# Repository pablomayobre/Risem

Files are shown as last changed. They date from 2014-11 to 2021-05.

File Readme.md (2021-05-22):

# Risem

[Risem](https://positive07.github.io/Risem/) is the final school project that we (my team and I) will work on.

We go to a Technical School and in our last year in this Highschool we make a final project to show the things that we learned over the last six years.

## Team

The team is composed by three persons:

*    Gutierrez Bianchi, Mora
*    Mayobre, Pablo Ariel
*    Mazzocca, Franco Gabriel

We are all students at the ESETP N°748 in Trelew, Chubut - Argentina, in the Electronics career. We are all 17 and in our last year of highschool (2014).

## The project

The school already has a Radio Station, with a HUGE Power Supply, a [Yaesu FT-857D](http://www.yaesu.com/indexVS.cfm?cmd=DisplayProducts&ProdCatID=102&encProdID=8CBB7C4BDBAF40129AD4253A4987523C) and other equipment.

Our aim is to use this station to receive images from the [NOAA Satellites](http://www.n2yo.com/satellites/?c=4), this can be done using a [Quadrifilar Helix (QFH)](http://www.g4ilo.com/qfh.html) antenna, but we wanted to use a [Crossed Yagi-Uda antenna](http://sv1bsx.50webs.com/antenna-pol/polarization.html), this means that we need to track the satellite and aim the antenna at it.

To reach our goal we intend to create a system composed of four main parts:

+   The antenna: A simple Yagi-Uda antenna calculated at the main frequency of the NOAA satellites
+   The rotator: A stepper motor drived, two axis rotator, that enables the antenna to move in azimuth and elevation
+   The controller system: Based around PIC micro-controller from [Microchip](http://www.microchip.com/). This communicates with the PC and commands the motors in the rotator
+   The software: A software that can communicate with the PIC through USB to send the data captured from GPredict

## Gpredict

[Gpredict](http://gpredict.oz9aec.net/) is a simple but really good software that can track satellites and calculate the azimuth, elevation and doppler effect correction in real time.

Also it can send this data over a TCP/IP connection to the [Hamlib's](http://sourceforge.net/projects/hamlib/) rigctld and rotctld utilities. The [protocols](https://github.com/Positive07/Risem/tree/master/Docs) used by this two softwares is available so we can easily replace them with our own software.

## NOAA Satellites

Why NOAA Satellites? They are cool!

No reason really, this project will be left in the school so it can be used as a didactic tool. The system can work with any satellite really, you just need to replace the antenna.

## Software

As stated above the software interacts with Gpredict through a TCP connection, but it also needs to have a simple user interface, and communicate with the control board. 
To do this we decided to use [LÖVE](http://www.love2d.org/) since that is the software I'm used to. 

LÖVE doesnt provide any interface to communicate with USB peripherials by default, so in order to communicate with the PIC we coded an intermediate app in C# (Visual Studio Express 2013), this app is a TCP server which offers access to the SerialPort class in .NET Framework.
Since C#, Visual Studio and .NET Framework are not Open Source we decided to minimze the code made using it. The TCP server can be replaced for other software with the same functionality allowing to easily port this program to other platforms.

## Controller Board

The controller is a home-built PCB made around the [PIC 18F4550](http://www.microchip.com/wwwproducts/Devices.aspx?dDocName=en010300), which offers an USB connection (Simulating a serial connection), a 16x2 Character Display (Used to display additional info), 2x L297 and L298 Stepper Motor Drivers, and a MAX232 serial connection (for CAT or other serial protocol).

The PIC will be programmed using MPLAB and the C18 compiler. The PCB was designed using EAGLE CAD 6.4.0

## Rotator

This will consist of two stepper motors, one to control the azimuth of the antenna, and another one to control the elevation.

The rotor will also use 2 worm reductions (one for azimuth and the other for elevation) of 1:30 ratio, to increment the torque an precission of the rotator.

## Antenna

The antenna is not a crucial part of the project, this can be easily replaced with any antenna, so no design instructions or such will be uploaded to this repo

## License

This project is Licensed under *MIT License* and Copyrighted by Mora Gutierrez, Pablo Mayobre and Franco Mazzocca.

### Contact

Send me a mail at [pablo.a.mayobre@gmail.com](mailto:pablo.a.mayobre@gmail.com) for more info.

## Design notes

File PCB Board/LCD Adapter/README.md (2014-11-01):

LCD Adapter
===========
This is a PCB made for the project **RISEM**. It's used to adapt the main board LCD terminals into a single row of pins, this allows the use of a parallel (plain) cable for the connection between the LCD board and the Main board

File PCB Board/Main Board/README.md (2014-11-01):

Main Board
==========
This is the main board of the project **RISEM**. It has many modules that allow for all the interactions that are needed. These modules are the following:

*    *USB Connection:* The main board needs to be connected to the PC in order to get the Azimuth, Elevation and Frequency.

*    *Motor Controllers:* There are two motors in an AzEl Rotor, both of them are stepper motors that need to be controlled individually, for this task the board is equiped with two L297-L298 pairs, which support steppers motors up to 2A.

*    *Serial Connection:* The frequency of the Yaesu FT-857D is corrected through the use of a Serial-CAT cable, which transforms the TTL CAT signals of the Yaesu into RS-232 USART signals, in the main board a MAX232 converts the RS-232 signals into TTL signals again, in order to connect the USART module in the PIC to the Yaesu CAT module.

*    *LCD Connection:* A requirement for this project is the use of an LCD, this project is designed to support characters displays (16x2 or 16x4) with 5x7 characters.

*    *Programming Header:* The board allows to reprogram the PIC whenever there is a firmware update through a programming header.

*    *Tension Regulator:* There is a 5V L7805 tension regulator in board. This allow to power the motors and the control board with a single supply.

*    *GPIO:* The port A was left unused, this pins are free so they can be used for future extensions.

**NOTE: The GPIO pins and the RESET buttons are hidden by the LCD Adapter, to use them they need to be connected through wires or other adapter board.**

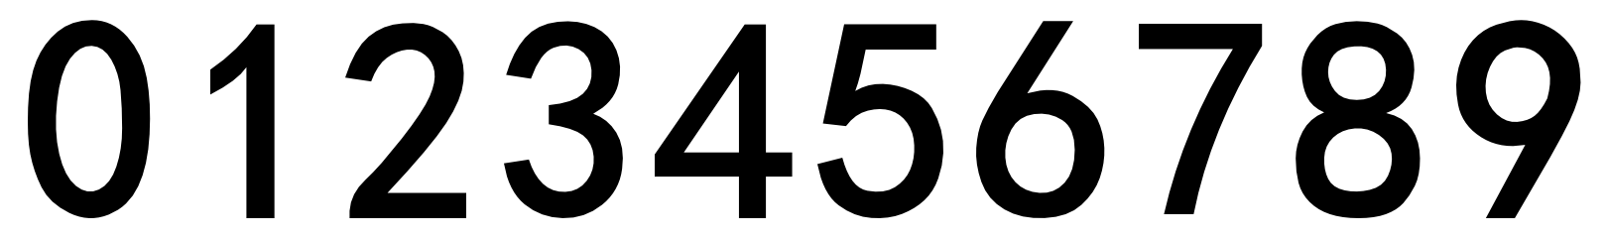
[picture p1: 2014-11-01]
PC Software/Main/assets/numbers.png

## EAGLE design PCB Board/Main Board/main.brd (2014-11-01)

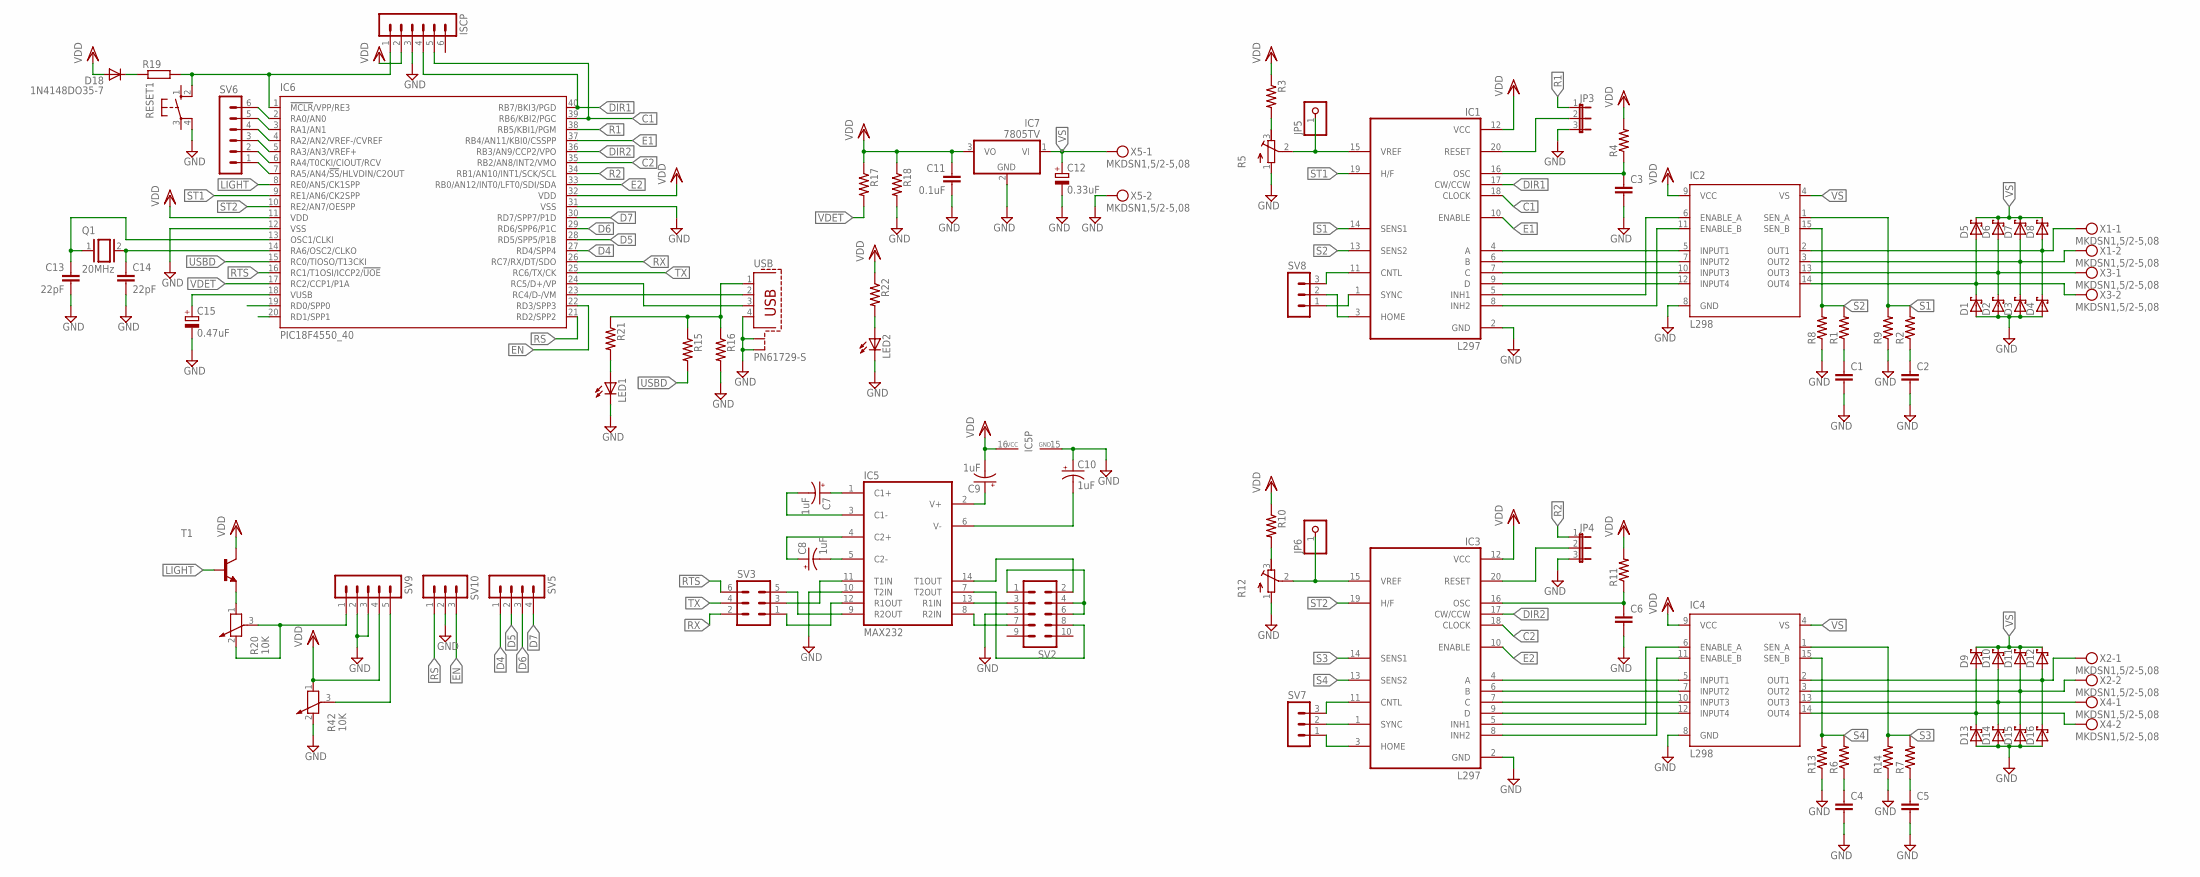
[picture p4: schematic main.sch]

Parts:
C1, C2, C3, C4, C5, C6: C2.5/2; C2.5-2
C7, C8, C9, C10: 1uF; E2,5-6
C11: 0.1uF; C025-025X050
C12: 0.33uF; E2,5-6
C13, C14: 22pF; C025-024X044
C15: 0.47uF; E2,5-6
D1, D2, D3, D4, D5, D6, D7, D8, D9, D10, D11, D12, D13, D14, D15, D16: SCHOTTKY-DIODEDO201T15; DO201T15
D18: 1N4148DO35-7; DO35-7
IC1, IC3: L297; DIL20
IC2, IC4: L298; MULTIWATT-15
IC5: MAX232; DIL16
IC6: PIC18F4550_40; DIL40
IC7: 7805TV; TO220V
ISCP: MA06-1
JP3, JP4: JP2E; JP2
JP5, JP6: PINHD-1X1; 1X01
LED1, LED2: LED5MM
Q1: 20MHz; QS
R1, R2, R3, R4, R6, R7, R10, R11, R15, R16, R17, R18, R21, R22: R-US_0204/7; 0204/7
R5, R12: R-TRIMM64Y; RTRIM64Y
R8, R9, R13, R14: R-US_0411/15; 0411/15
R19: R-EU_0204/7; 0204/7
R20, R42: 10K; PT-10
RESET1: 10-XX; B3F-10XX
SV2: MA05-2
SV3: MA03-2
SV5: MA04-1
SV6: MA06-1
SV7, SV8, SV10: MA03-1
SV9: MA05-1
T1: BC548-NPN-TO92-CBE; TO92-CBE
USB: PN61729-S
X1, X2, X3, X4, X5: MKDSN1,5/2-5,08

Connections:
C1: IC1.18 (CLOCK), IC6.39 (RB6/KBI2/PGC), ISCP.5
C2: IC3.18 (CLOCK), IC6.35 (RB2/AN8/INT2/VMO)
D4: IC6.27 (RD4/SPP4), SV5.1
D5: IC6.28 (RD5/SPP5/P1B), SV5.2
D6: IC6.29 (RD6/SPP6/P1C), SV5.3
D7: IC6.30 (RD7/SPP7/P1D), SV5.4
DIR1: IC1.17 (CW/CCW), IC6.40 (RB7/BKI3/PGD), ISCP.4
DIR2: IC3.17 (CW/CCW), IC6.36 (RB3/AN9/CCP2/VPO)
E1: IC1.10 (ENABLE), IC6.37 (RB4/AN11/KBI0/CSSPP)
E2: IC3.10 (ENABLE), IC6.33 (RB0/AN12/INT0/LFT0/SDI/SDA)
EN: IC6.22 (RD3/SPP3), SV10.3
GND: C1.2, C2.2, C3.2, C4.2, C5.2, C6.2, C10.+, C11.2, C12.-, C13.2, C14.2, C15.-, D1.A, D2.A, D3.A, D4.A, D13.A, D14.A, D15.A, D16.A, IC1.2 (GND), IC2.8 (GND), IC3.2 (GND), IC4.8 (GND), IC5.10 (T2IN), IC5.15 (GND), IC6.12 (VSS), IC6.31 (VSS), IC7.2 (GND), ISCP.3, JP3.3, JP4.3, LED1.K (C), LED2.K (C), R5.1 (E), R8.1, R9.1, R12.1 (E), R13.1, R14.1, R16.2, R18.2, R42.2, RESET1.4 (P1), SV2.5, SV9.2, SV9.3, SV10.2, USB.4, USB.S1, USB.S2, X5.2
LIGHT: IC6.8 (RE0/AN5/CK1SPP), T1.B
unnamed: IC1.4 (A), IC2.5 (INPUT1)
unnamed: IC1.8 (INH2), IC2.11 (ENABLE_B)
unnamed: IC1.9 (D), IC2.12 (INPUT4)
unnamed: IC1.7 (C), IC2.10 (INPUT3)
unnamed: IC1.6 (B), IC2.7 (INPUT2)
unnamed: IC1.5 (INH1), IC2.6 (ENABLE_A)
unnamed: C1.1, R1.1
unnamed: C2.1, R2.1
unnamed: IC3.9 (D), IC4.12 (INPUT4)
unnamed: IC3.7 (C), IC4.10 (INPUT3)
unnamed: D4.C, D8.A, IC2.2 (OUT1), X1.1
unnamed: D3.C, D7.A, IC2.3 (OUT2), X1.2
unnamed: D2.C, D6.A, IC2.13 (OUT3), X3.1
unnamed: D1.C, D5.A, IC2.14 (OUT4), X3.2
unnamed: R3.2, R5.3 (A)
unnamed: IC5.11 (T1IN), SV3.3
unnamed: C3.1, IC1.16 (OSC), R4.1
unnamed: IC3.6 (B), IC4.7 (INPUT2)
unnamed: IC3.4 (A), IC4.5 (INPUT1)
unnamed: IC3.8 (INH2), IC4.11 (ENABLE_B)
unnamed: IC3.5 (INH1), IC4.6 (ENABLE_A)
unnamed: C4.1, R6.1
unnamed: C5.1, R7.1
unnamed: D12.A, D16.C, IC4.2 (OUT1), X2.1
unnamed: D11.A, D15.C, IC4.3 (OUT2), X2.2
unnamed: D10.A, D14.C, IC4.13 (OUT3), X4.1
unnamed: D9.A, D13.C, IC4.14 (OUT4), X4.2
unnamed: R10.2, R12.3 (A)
unnamed: IC3.15 (VREF), JP6.1, R12.2 (S)
unnamed: C6.1, IC3.16 (OSC), R11.1
unnamed: IC5.13 (R1IN), SV2.3
unnamed: IC3.11 (CNTL), SV7.3
unnamed: IC5.9 (R2OUT), SV3.5
unnamed: IC5.12 (R1OUT), SV3.1
unnamed: R15.1, R16.1, R21.1, USB.1
unnamed: C13.1, IC6.13 (OSC1/CLKI), Q1.1
unnamed: C14.1, IC6.14 (RA6/OSC2/CLKO), Q1.2
unnamed: IC1.20 (RESET), JP3.2
unnamed: IC6.1 (!MCLR!/VPP/RE3), ISCP.1, R19.2, RESET1.2 (S1)
unnamed: D18.C, R19.1
unnamed: IC3.20 (RESET), JP4.2
unnamed: IC3.1 (SYNC), SV7.2
unnamed: IC3.3 (HOME), SV7.1
unnamed: IC1.11 (CNTL), SV8.3
unnamed: IC1.3 (HOME), SV8.2
unnamed: IC1.1 (SYNC), SV8.1
unnamed: IC6.2 (RA0/AN0), SV6.6
unnamed: R20.1, T1.E
unnamed: IC6.3 (RA1/AN1), SV6.5
unnamed: SV2.1, SV2.4, SV2.6
unnamed: R20.2, R20.3, SV9.1
unnamed: IC5.14 (T1OUT), SV2.2
unnamed: IC5.7 (T2OUT), SV2.8
unnamed: IC5.8 (R2IN), SV2.7
unnamed: IC6.4 (RA2/AN2/VREF-/CVREF), SV6.4
unnamed: IC6.5 (RA3/AN3/VREF+), SV6.3
unnamed: IC6.6 (RA4/T0CKI/CIOUT/RCV), SV6.2
unnamed: IC6.7 (RA5/AN4/!SS!/HLVDIN/C2OUT), SV6.1
unnamed: LED1.A, R21.2
unnamed: LED2.A, R22.2
unnamed: C15.+, IC6.18 (VUSB)
unnamed: IC6.23 (RC4/D-/VM), USB.2
unnamed: IC6.24 (RC5/D+/VP), USB.3
unnamed: C8.-, IC5.5 (C2-)
unnamed: IC1.15 (VREF), JP5.1, R5.2 (S)
unnamed: C8.+, IC5.4 (C2+)
unnamed: C7.+, IC5.1 (C1+)
unnamed: C7.-, IC5.3 (C1-)
unnamed: C9.+, IC5.2 (V+)
unnamed: C10.-, IC5.6 (V-)
unnamed: R42.3, SV9.5
R1: IC6.38 (RB5/KBI1/PGM), JP3.1
R2: IC6.34 (RB1/AN10/INT1/SCK/SCL), JP4.1
RS: IC6.21 (RD2/SPP2), SV10.1
RTS: IC6.16 (RC1/T1OSI/ICCP2/!UOE), SV3.6
RX: IC6.26 (RC7/RX/DT/SDO), SV3.2
S1: IC1.14 (SENS1), IC2.1 (SEN_A), R2.2, R9.2
S2: IC1.13 (SENS2), IC2.15 (SEN_B), R1.2, R8.2
S3: IC3.14 (SENS1), IC4.1 (SEN_A), R7.2, R14.2
S4: IC3.13 (SENS2), IC4.15 (SEN_B), R6.2, R13.2
ST1: IC1.19 (H/F), IC6.9 (RE1/AN6/CK2SPP)
ST2: IC3.19 (H/F), IC6.10 (RE2/AN7/OESPP)
TX: IC6.25 (RC6/TX/CK), SV3.4
USBD: IC6.15 (RC0/TIOSO/T13CKI), R15.2
VDD: C9.-, C11.1, D18.A, IC1.12 (VCC), IC2.9 (VCC), IC3.12 (VCC), IC4.9 (VCC), IC5.16 (VCC), IC6.11 (VDD), IC6.32 (VDD), IC7.3 (VO), ISCP.2, R3.1, R4.2, R10.1, R11.2, R17.1, R18.1, R22.1, R42.1, SV9.4, T1.C
VDET: IC6.17 (RC2/CCP1/P1A), R17.2
VS: C12.+, D5.C, D6.C, D7.C, D8.C, D9.C, D10.C, D11.C, D12.C, IC2.4 (VS), IC4.4 (VS), IC7.1 (VI), X5.1

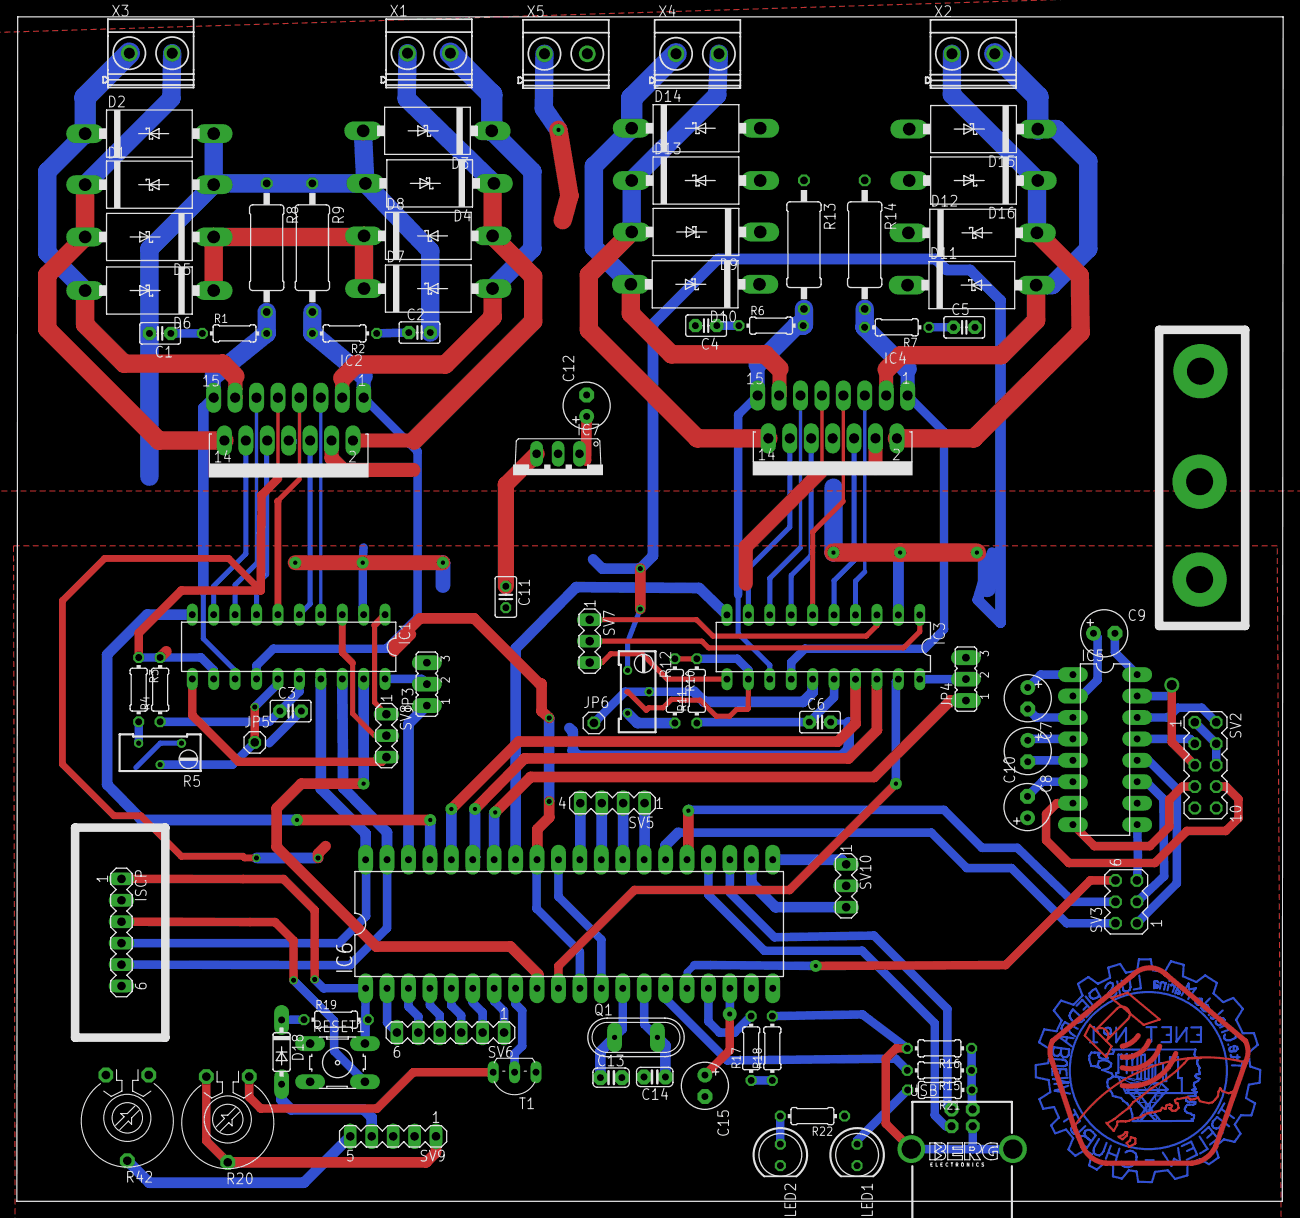
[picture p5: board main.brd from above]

Board: 2 copper layers, 150.1 x 140.4 mm, 87 parts (0 on the bottom side), 100 nets.

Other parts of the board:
RW: LOGOENET

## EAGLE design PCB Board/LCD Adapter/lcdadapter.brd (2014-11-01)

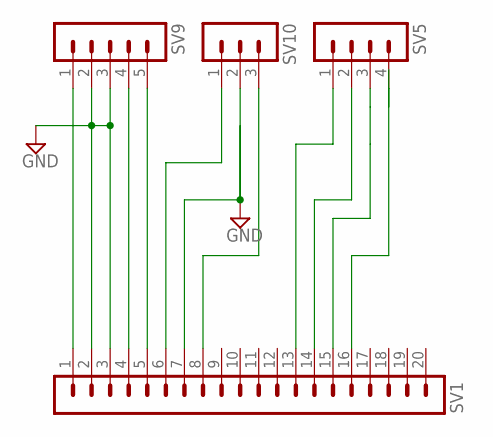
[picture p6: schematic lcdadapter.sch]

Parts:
SV1: MA20-1L
SV5: MA04-1
SV9: MA05-1
SV10: MA03-1

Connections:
D4: SV1.13, SV5.1
D5: SV1.14, SV5.2
D6: SV1.15, SV5.3
EN: SV1.8, SV10.3
unnamed: SV1.16, SV5.4
unnamed: SV1.4, SV9.4
unnamed: SV1.1, SV9.1
unnamed: SV1.2, SV1.3, SV1.7, SV9.2, SV9.3, SV10.2
unnamed: SV1.5, SV9.5
RS: SV1.6, SV10.1

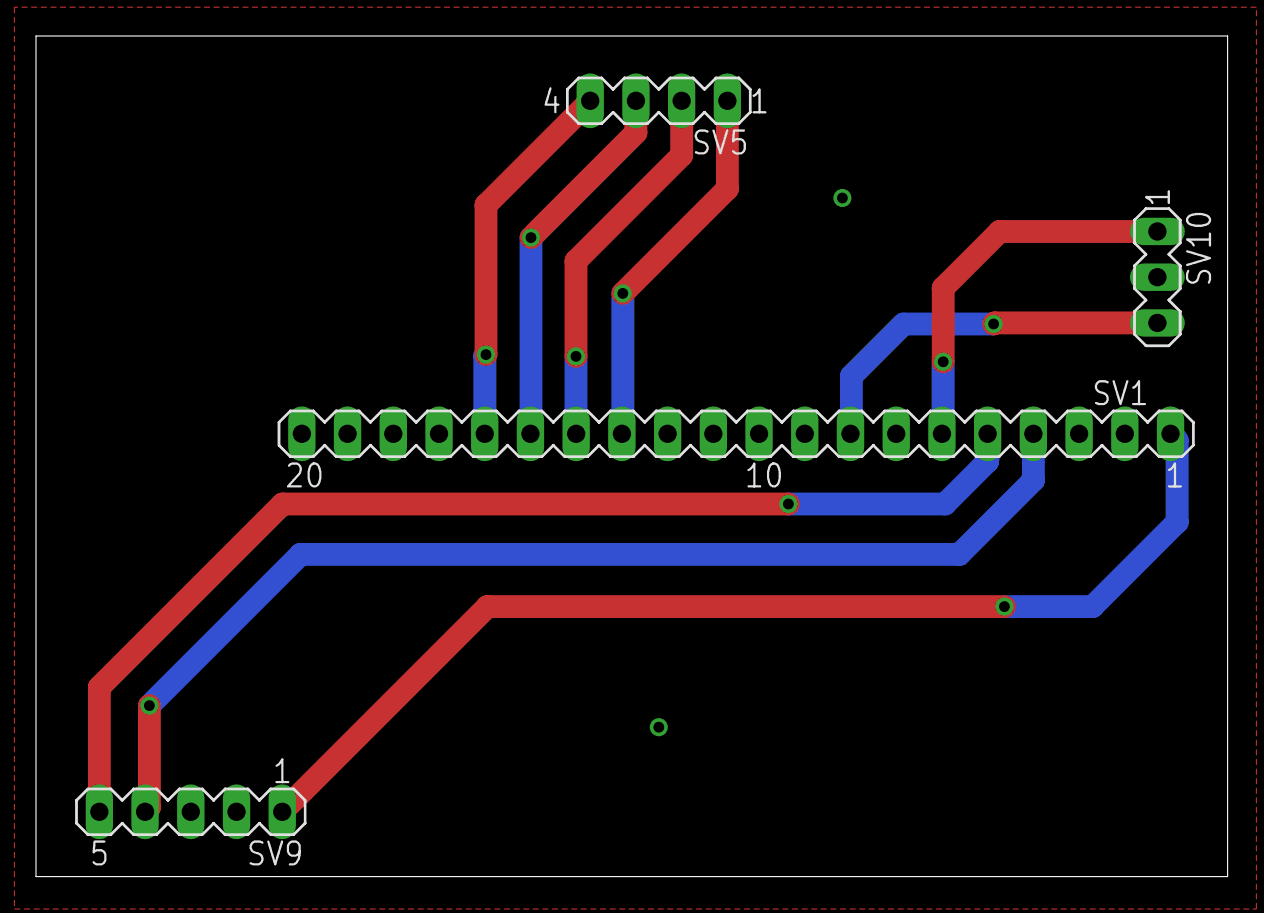
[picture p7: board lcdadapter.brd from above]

Board: 2 copper layers, 66.2 x 46.7 mm, 4 parts (0 on the bottom side), 10 nets.

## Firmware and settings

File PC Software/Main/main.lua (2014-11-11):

io.stdout:setvbuf("no")

local principal = require "principal"
local ports = require "ports"
require "conversion"
local scale = 1.4

tocart = function (elevation,angle)
	local radius = 1 - (elevation / 90)
	angle = math.rad(angle)
	return radius * math.cos(angle), radius * math.sin(angle)
end

startup = true

local states = {
	EL = {0,0,0};
	AZ = {0,0,0,0};
	FR = {0,0,0,0,0,0,0,0,0};
	RADIOSTATE = "manual";
	ROTORSTATE = "manual";
	LOGO = 0;
}

func = require "func"

love.load = function ()
	ra = love.thread.newThread("radio.lua")
	radio = love.thread.newChannel()
	ra:start(radio)

	--Inicia el programa de rotor y genera una conexion para comunicarse con el mismo
	ro = love.thread.newThread("rotor.lua")
	rotor = love.thread.newChannel()
	ro:start(rotor)

	love.window.setMode(580 * scale,315 * scale)
	love.window.setTitle("Risem")
	love.window.setIcon(love.image.newImageData("assets/logo.png"))
	
	logo = love.graphics.newImage("assets/logo.png")
	risem = love.graphics.newImage("assets/risem.png")
	arial = love.graphics.newFont("assets/arialbd.ttf",12 * scale)
	little = love.graphics.newFont("assets/arial.ttf",11 * scale)
	
	thread = love.thread.newThread("serial.lua")
	transmit = love.thread.getChannel("transmit")
	receive = love.thread.getChannel("receive")

	quit = love.thread.newChannel()
	thread:start(quit)

	channels = {tx = transmit,rx = receive}
	
	btn.x = (love.graphics.getWidth() - btn.w)/2
	btn.y = (love.graphics.getHeight() - 100 - btn.h)/2
end
local conv = function (val)
	return string.format("%03d.%01d",math.floor(val),val % 1 * 10)
end
local time = 0
love.update = function (dt)
	while receive:getCount() > 0 do
		local msg = receive:pop()
		if msg then
			if type(msg) == "table" then
				if msg[1] == "ports" then
					Option = {}
					for k,v in ipairs(msg) do
						if k ~= 1 then
							Option[#Option + 1] = v
						end
					end
				end
			else
				if msg:match("%[RX%](.*)") then
					--Received something from the PIC YEAH!
					print(msg:match("%[RX%](.*)"))
				elseif msg:match("%[E%](.*)") then
					StartupError = msg:match("%[E%](.*)")
					--Oh no! Errors!
					print(msg:match("%[E%](.*)"))
				else
					if msg == "State = open" then
						startup = false
					elseif msg == "DISCONNECTED" then
						startup = true
					end
					print(msg)
					--A Serial message (Maybe a TX or innecessary data... at least to the user)
				end
			end
		end
	end
	if startup then
		ports.update(dt)
	else
		time = time + dt
		if time > 3 and somethingchanged then
			func.send("","AZ:"..tostring(tonumber(table.concat(states.AZ))/10))
			func.send("","EL:"..tostring(tonumber(table.concat(states.EL))/10))
			local val = tohex(tonumber("0x"..table.concat(states.FR),16))
			func.send("","FQ:"..val)
			print(string.format("%x",todec(val)))
			somethingchanged = false
			time = 0
		end
		if states.LOGO >= 10 then 
			print "THIS IS A SECRET MESSAGE"
			states.LOGO = 0 
		end
		if states.RADIOSTATE == "gpredict" then
			local frequency, radi
			while radio:getCount() > 0 do
				radi = radio:pop()
			end
			if radi then 
				frequency = tonumber(radi)
				frz = string.format("%09d",frequency)
				for i=1,#frz do
					states.FR[i] = tonumber(frz:sub(i,i))
				end
			end
		end
		if states.ROTORSTATE == "gpredict" then
			local azimuth, elevation, roto
			while rotor:getCount() > 0 do
				roto = rotor:pop()
			end
			if roto then 
				elevation = tonumber(roto:sub(1,roto:find(",") - 1)) or 0
				azimuth = tonumber(roto:sub(roto:find(",") + 1)) or 0
				local azz = conv(azimuth)
				local elz = conv(elevation)
				local j,k = 1,1
				for i=1, 5 do
					states.AZ[j] = tonumber(azz:sub(i,i))
					if i ~= 5 then states.EL[k] = tonumber(elz:sub(i,i)) end
					if i ~= 3 then k = k + 1 end
					if i ~= 4 then j = j + 1 end
				end
			end
		end
	end
end

love.draw = function ()
	principal.draw(scale,states)
	if startup then
		love.graphics.setColor(0,0,0,200)
		love.graphics.rectangle("fill",0,0,love.window.getWidth(), love.window.getHeight())
		ports.draw()
	end
end

love.mousepressed = function (x,y,b)
	if startup then
		ports.mousepressed(b,x,y)
	else
		principal.mousepressed(x,y,b,scale,states)
	end
end

love.mousereleased = function (x,y,b)
	if startup then
		ports.mousereleased(b,x,y)
	end
end

function love.threaderror(thread, errorstr)
	--Imprime los errores de los programas Radio y Rotor si algo falla
	print("Thread error!\n"..errorstr)
end

function love.quit ()
	func.close()
	quit:push("EXIT")
	thread:wait()
end

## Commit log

2014-11-01 Added PCB Board
    Added the PCB Boards designs, made in EAGLE CAD. This are the last
    iteration of the project
    [lcdadapter.brd, lcdadapter.sch, main.brd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]
2014-11-01 Main board description update
